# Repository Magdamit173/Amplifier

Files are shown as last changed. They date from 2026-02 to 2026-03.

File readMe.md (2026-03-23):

# Multi-Stage BJT Amplifier (v2.0)

A high-gain, dual-stage BJT amplifier project designed for the **Stage II (March 26)** milestone. This design is optimized for fabrication on a **presensitized PCB** with a compact footprint.

### Design Specifications
* **Target Gain ($A_v$):** $\ge 120$
* **Frequency Range (Ideal):** $80\text{Hz}$ to $20\text{kHz}$
* **Board Dimensions:** $2.2480 \times 1.1496$ inches
* **Trace Clearance:** $0.300\text{mm}$ ~ $0.400\text{mm}$ 
* **Track Width:** $0.850\text{mm}$ ~ $1.000\text{mm}$ 
* **Filled Zone (Notice ⚠️):** $0.400\text{mm}$
* **Fabrication Method:** Presensitized PCB

| Contributors | Main Role | Responsibilities |
| --- | --- | --- |
| Anday, John Kevin I. | Logistics |Component sourcing and technical specification sourcing. |
| Haque, Majeed P. | Technical Director (Leader) [Amplifier Circuit](/NI%20Multisim/Amplifier.ms14) | Mathematical modeling, circuit analysis, and core calculations. |
| Leonardo, John Ruiz | Quality Assurance |Validation of engineering calculations and design accuracy.|
| Magdamit, Rovic | Hardware/PCB, and Documentation [github](./)| Design layout, footprint selection. |
| Obar, Tohms Hegel V. | Documentation Head | Technical reporting, citation research, and presentation design.|

### Component Notes
* **Coupling Capacitors:** 10µF 50V **Monolithic Ceramics** (Code 106).
* **Bypass Capacitors:** 33µF **16V** Electrolytics.
* **Note:** Monolithic capacitors are utilized in this design as the primary representation for high-value ceramic components to ensure a compact and stable PCB layout.

### Components (Table of Expense)

| Category | Component Description | Qty | Unit Price (PHP) | Total (PHP) | Reference Link |
| :--- | :--- | :---: | :---: | :---: | :--- |
| **Active** | BC547 NPN Transistor (Unsorted) | 1 | ₱0.83 | ₱0.83 | [Shopee (100pcs)](https://shopee.ph/100pcs-BC547-TO-92-NPN-transistor-i.119376932.27625517704) |
| **Active** | 2N3904 NPN Transistor | 1 | ₱0.96 | ₱0.96 | [Shopee (50pcs)](https://shopee.ph/50PCS-2N3904-2N3906-2N4403-2N2907-2N4401-2N2222-PN2222-2N5401-2N5551-TO-92-TO92-Transistor-New-i.1130255612.20395632930) |
| **Capacitors** | 10µF 50V Monolithic Ceramic (106) | 3 | ₱0.98 | ₱2.94 | [Shopee (50pcs)](https://shopee.ph/product/497215439/24193377802) |
| **Capacitors** | 33µF 16V Electrolytic | 2 | ₱3.60 | ₱7.20 | [Shopee (5pcs)](https://shopee.ph/Electrolytic-Capacitor-16V-25V-35V-50V-i.535662606.26003134704) |
| **Resistors** | 1/4W Metal Film Resistors | 11 | ₱3.00 | ₱33.00 | Local Retail |
| **Connectors** | 2-Pin Screw Terminal (5.0mm) | 3 | ₱4.20 | ₱12.60 | [Shopee (10pcs)](https://shopee.ph/10Pcs-KF301-2P-Screw-5.0mm-Terminal-Block-i.487295469.12046517038) |
| **Fabrication**| **Presensitized PCB (4x6 inches)** | 1 | **₱205.00** | **₱205.00** | [Lazada (Alexan)](https://www.lazada.com.ph/products/with-developer-alexan-presensitized-pcb-4x6-i1380024544.html) |
| **TOTAL** | | | | **₱261.53** | |

*Note: Unit prices are derived from bulk pack listings (Shopee/Lazada) to reflect actual prototype cost.*

### Design Documentation

#### Schematic Diagram
Schematic

### PCB Layout & 3D Preview
| 2D Copper Trace View | 3D Rendered View |
| :--- | :--- |
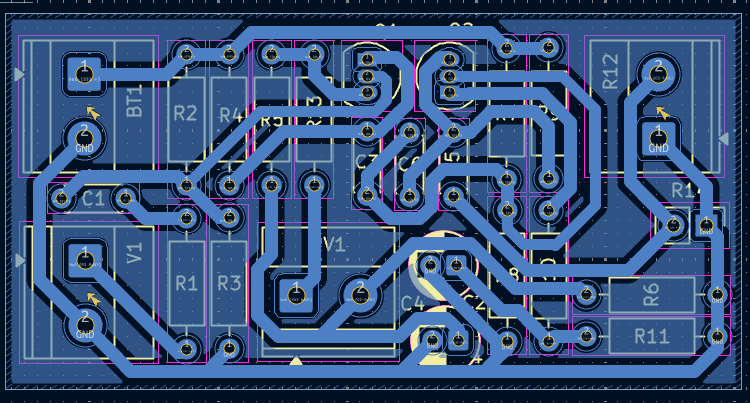
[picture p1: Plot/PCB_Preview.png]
PCB 2D
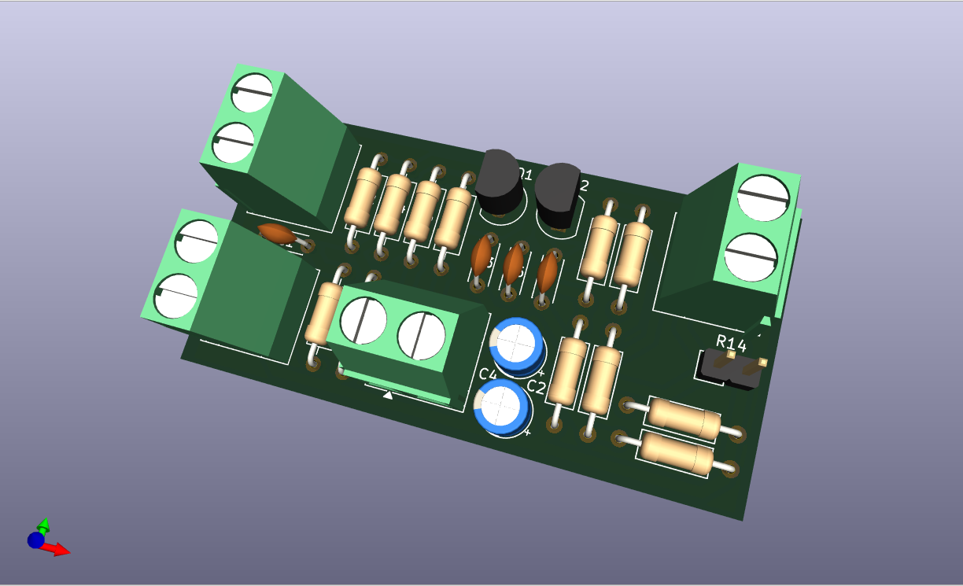
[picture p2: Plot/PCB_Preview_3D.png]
PCB 3D
|  |  |

### Repository Structure
* **`/Plot`**: Contains exported manufacturing files (SVG/PNG).

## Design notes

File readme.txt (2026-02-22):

BC547 100pcs (unsorted) - ₱83 : https://shopee.ph/100pcs-BC547-TO-92-NPN-transistor-i.119376932.27625517704

2N3904 50pcs - ₱48 : https://shopee.ph/50PCS-2N3904-2N3906-2N4403-2N2907-2N4401-2N2222-PN2222-2N5401-2N5551-TO-92-TO92-Transistor-New-i.1130255612.20395632930

Monolithic Ceramic Capacitor (10uf 50v) 50pcs - ₱49 : https://shopee.ph/product/497215439/24193377802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

Electrolytic capacitor (33uf 16v) 5pcs - 18 pesos: 
https://shopee.ph/Electrolytic-Capacitor-16V-25V-35V-50V-with-various-capacitance-i.535662606.26003134704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

1/4W Metal Film Resistors 11pcs : Can be bought on local stores, each 1 wouldn't be greater than 2 pesos

screw terminal 10Pcs -  42 pesos: https://shopee.ph/10Pcs-KF301-2P-Screw-5.0mm-Terminal-Block-2-Pin-3-Pin-Pcb-Terminal-Block-Connector-i.487295469.12046517038

Alexan Presensitized PCB (4"x6") - ₱205 : https://www.lazada.com.ph/products/with-developer-alexan-presensitized-pcb-4x6-i1380024544.html

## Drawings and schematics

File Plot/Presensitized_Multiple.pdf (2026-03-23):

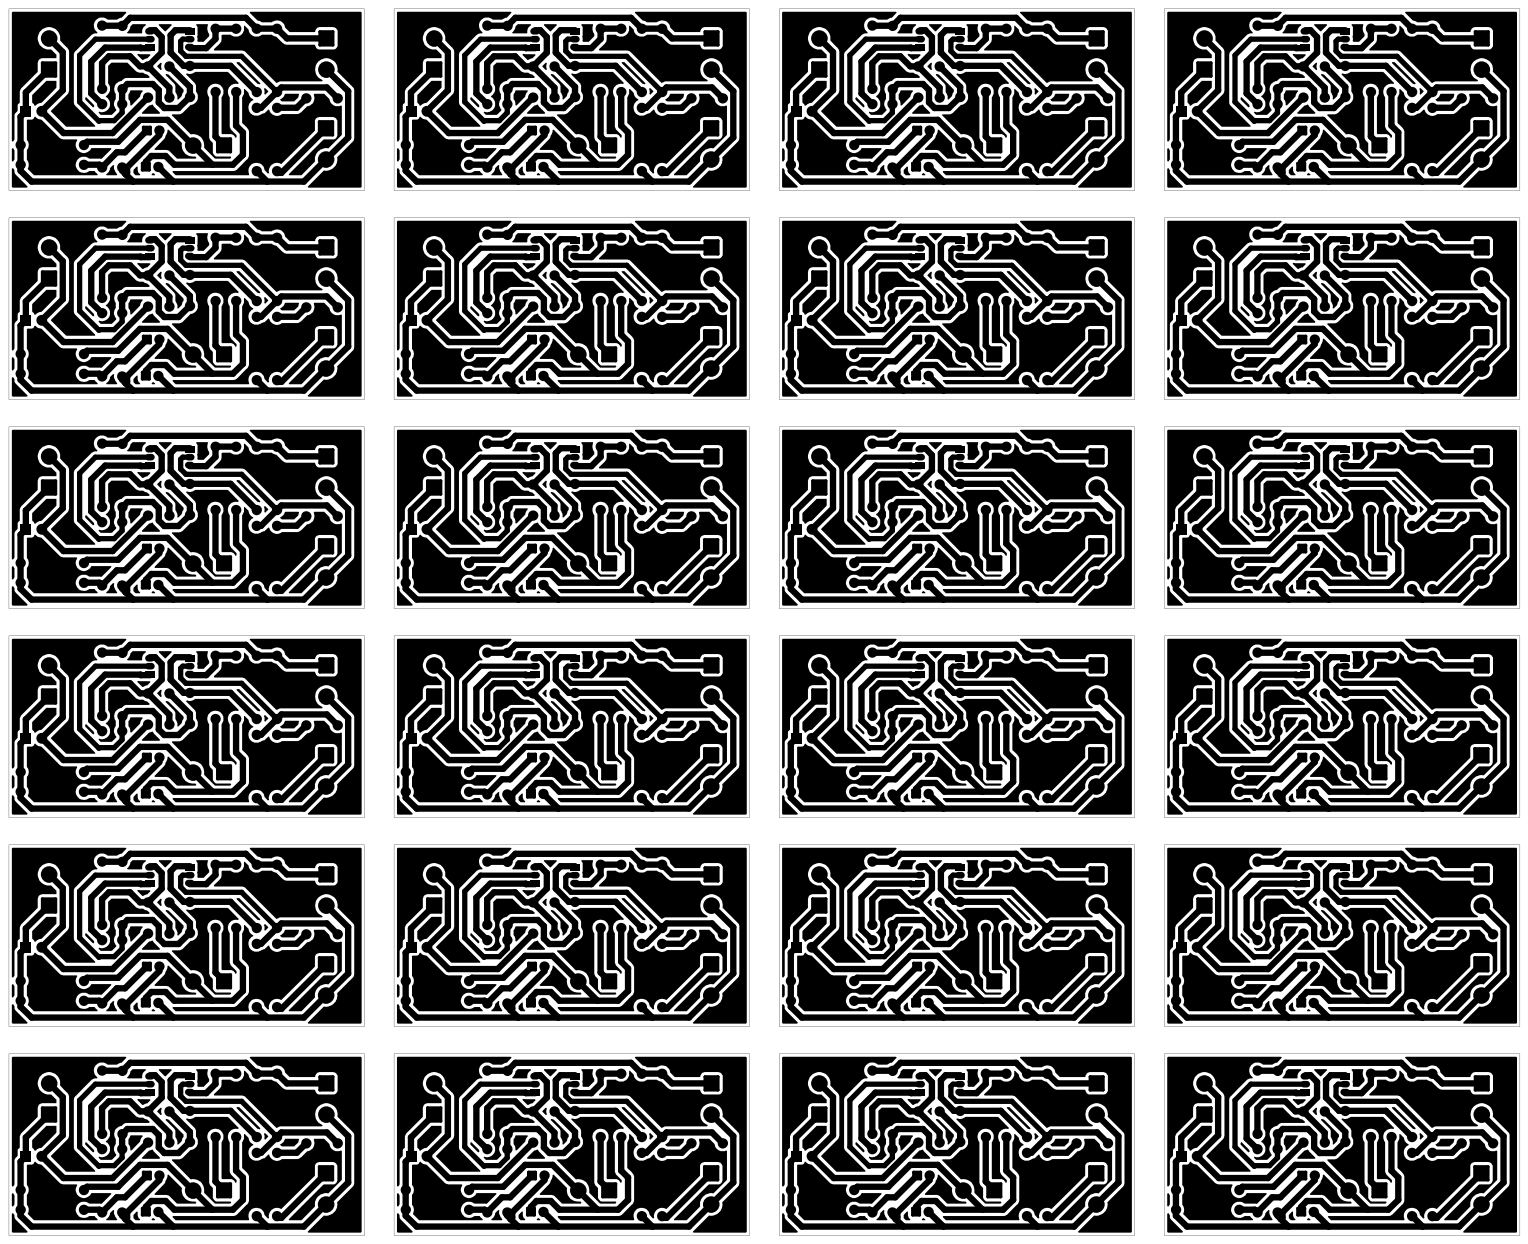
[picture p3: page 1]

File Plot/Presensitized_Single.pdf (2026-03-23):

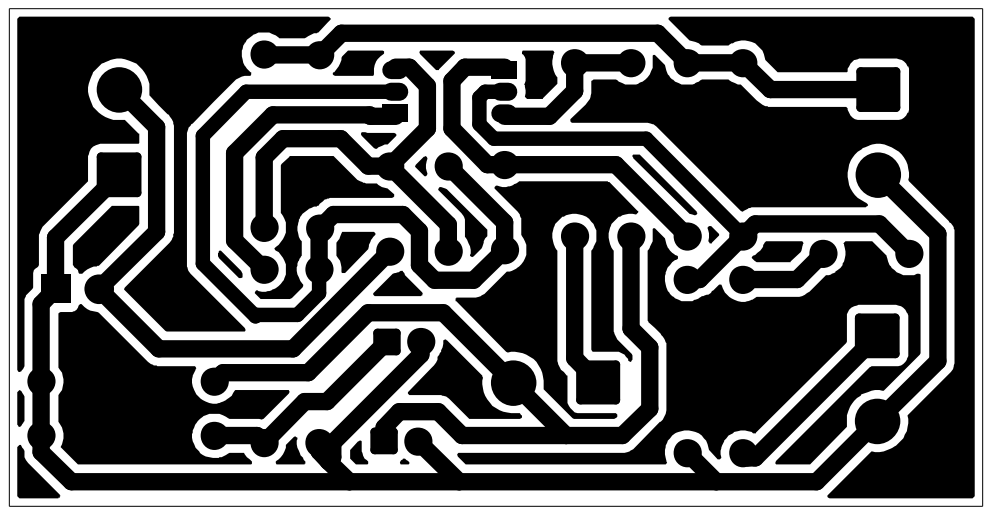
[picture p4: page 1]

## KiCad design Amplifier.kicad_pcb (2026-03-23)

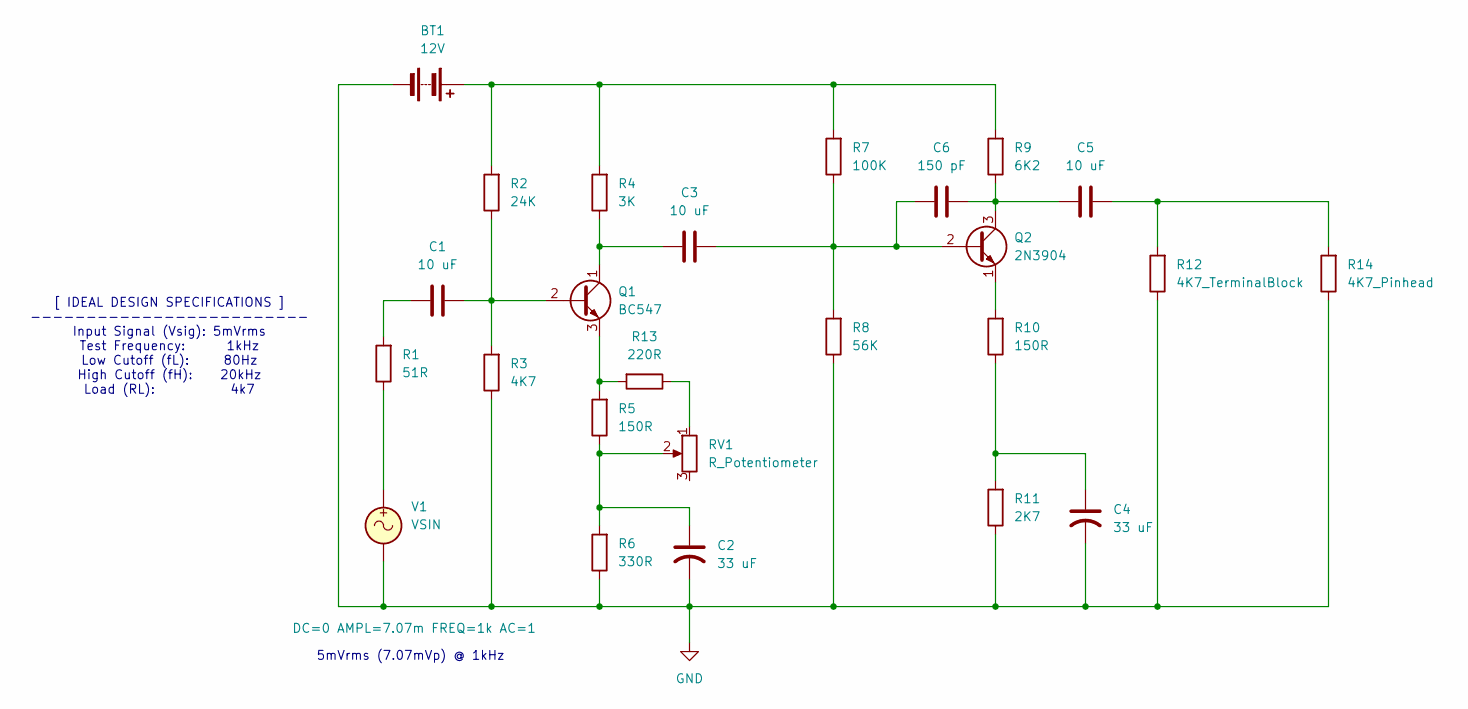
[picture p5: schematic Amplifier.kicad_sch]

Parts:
BT1: 12V; TerminalBlock_Phoenix_MKDS-1,5-2_1x02_P5.00mm_Horizontal
C1, C3, C5: 10 uF; C_Disc_D4.3mm_W1.9mm_P5.00mm
C2, C4: 33 uF; CP_Radial_D5.0mm_P2.00mm
C6: 150 pF; C_Disc_D4.3mm_W1.9mm_P5.00mm
Q1: BC547; TO-92_Inline
Q2: 2N3904; TO-92_Inline
R1: 51R; R_Axial_DIN0207_L6.3mm_D2.5mm_P10.16mm_Horizontal
R2: 24K; R_Axial_DIN0207_L6.3mm_D2.5mm_P10.16mm_Horizontal
R3: 4K7; R_Axial_DIN0207_L6.3mm_D2.5mm_P10.16mm_Horizontal
R4: 3K; R_Axial_DIN0207_L6.3mm_D2.5mm_P10.16mm_Horizontal
R5, R10: 150R; R_Axial_DIN0207_L6.3mm_D2.5mm_P10.16mm_Horizontal
R6: 330R; R_Axial_DIN0207_L6.3mm_D2.5mm_P10.16mm_Horizontal
R7: 100K; R_Axial_DIN0207_L6.3mm_D2.5mm_P10.16mm_Horizontal
R8: 56K; R_Axial_DIN0207_L6.3mm_D2.5mm_P10.16mm_Horizontal
R9: 6K2; R_Axial_DIN0207_L6.3mm_D2.5mm_P10.16mm_Horizontal
R11: 2K7; R_Axial_DIN0207_L6.3mm_D2.5mm_P10.16mm_Horizontal
R12: 4K7_TerminalBlock; TerminalBlock_Phoenix_MKDS-1,5-2_1x02_P5.00mm_Horizontal
R13: 220R; R_Axial_DIN0207_L6.3mm_D2.5mm_P10.16mm_Horizontal
R14: 4K7_Pinhead; PinHeader_1x02_P2.54mm_Vertical
RV1: R_Potentiometer; TerminalBlock_Phoenix_MKDS-1,5-2_1x02_P5.00mm_Horizontal
V1: VSIN; TerminalBlock_Phoenix_MKDS-1,5-2_1x02_P5.00mm_Horizontal

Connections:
GND: BT1.2 (-), C2.2, C4.2, R3.1, R6.1, R8.1, R11.1, R12.1, R14.1, V1.2
unnamed: BT1.1 (+), R2.2, R4.2, R7.2, R9.2
unnamed: C1.1, R1.2
unnamed: C2.1, R5.1, R6.2, RV1.2
unnamed: C4.1, R10.1, R11.2
unnamed: C5.1, R12.2, R14.2
unnamed: C1.2, Q1.2 (B), R2.1, R3.2
unnamed: C3.1, Q1.1 (C), R4.1
unnamed: Q1.3 (E), R5.2, R13.2
unnamed: C3.2, C6.2, Q2.2 (B), R7.1, R8.2
unnamed: C5.2, C6.1, Q2.3 (C), R9.1
unnamed: Q2.1 (E), R10.2
unnamed: R1.1, V1.1
unnamed: R13.1, RV1.1

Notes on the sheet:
[ IDEAL DESIGN SPECIFICATIONS ] ------------------------- Input Signal (Vsig): 5mVrms Test Frequency: 1kHz Low Cutoff (fL): 80Hz High Cutoff (fH): 20kHz Load (RL): 4k7
5mVrms (7.07mVp) @ 1kHz

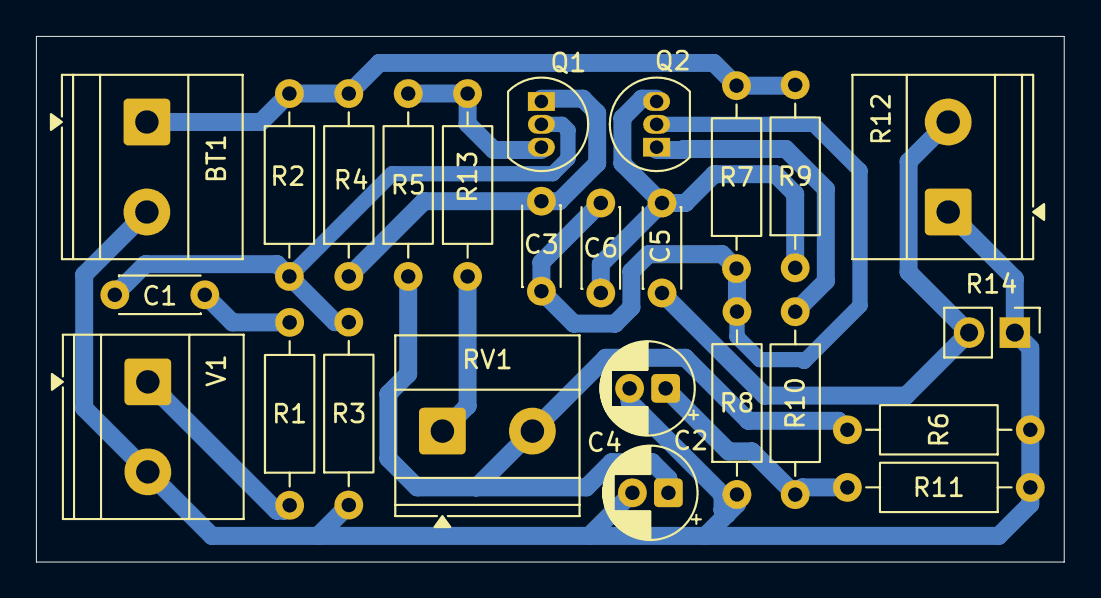
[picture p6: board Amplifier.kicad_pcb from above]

Board: 2 copper layers, 57.1 x 29.2 mm, 25 parts (0 on the bottom side), 14 nets.

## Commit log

2026-02-21 version 1: 2.22.2026
    [Power_Amplifier.kicad_pcb, Power_Amplifier.kicad_sch]
2026-02-26 Change title from 'Power Amplifier' to 'Amplifier'
    Updated the title to reflect the project as an amplifier.
2026-03-23 v2.0 3.24.2026
    [Amplifier.kicad_pcb, Amplifier.kicad_sch]
